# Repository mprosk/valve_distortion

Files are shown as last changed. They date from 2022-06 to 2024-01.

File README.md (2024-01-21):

# Valve Distortion
Eurorack format reimplementation of the Safety Valve from Look Mum No Computer

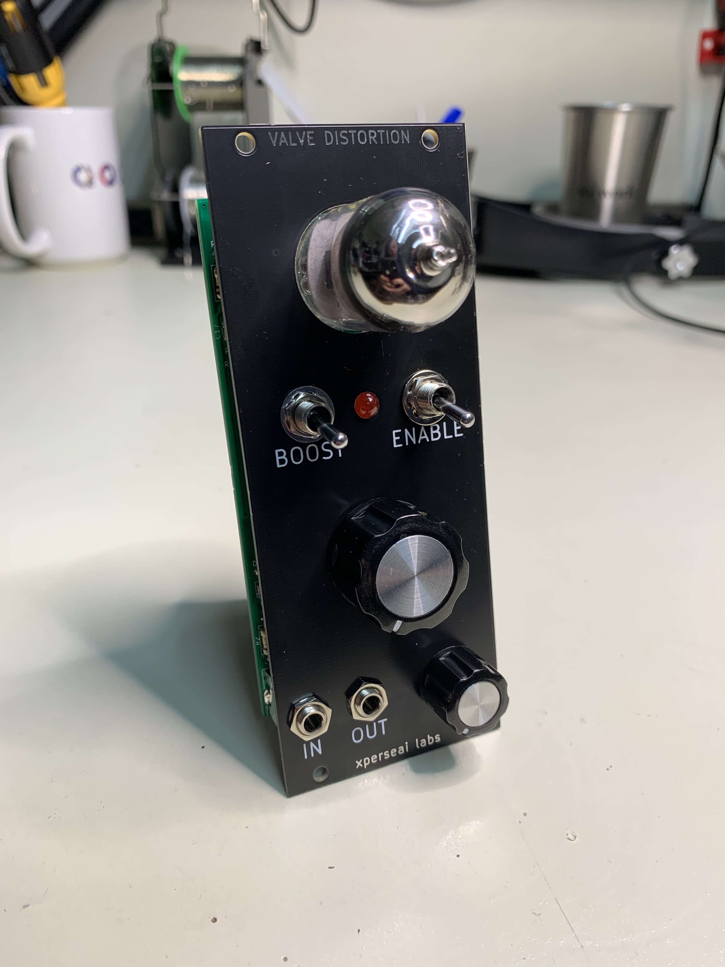
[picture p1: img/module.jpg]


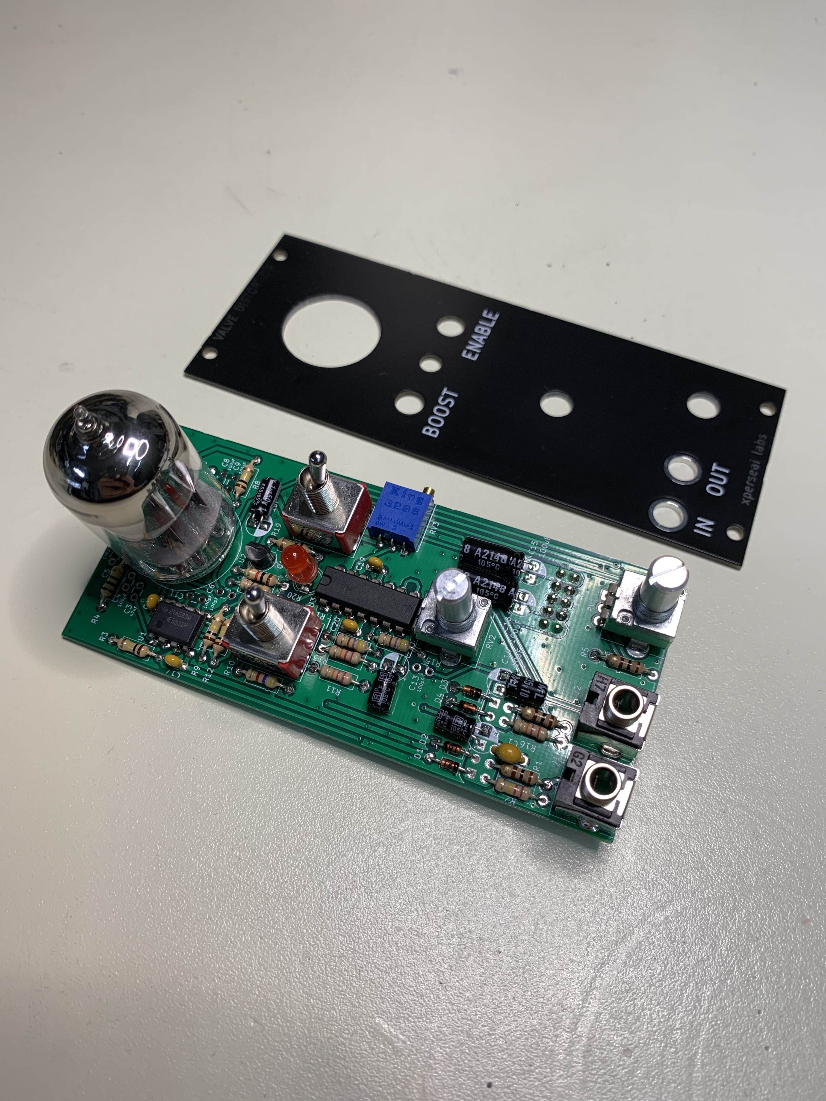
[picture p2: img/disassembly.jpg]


## Assembly Instructions

**Step 1:** Solder all resistors and diodes. Resistor values are marked on the silkscreen. **Be sure to get the correct orientation of the diodes!**

**Step 2:** Solder the ceramic capacitors. Ceramic capacitor values are marked on the silkscreen, *with the exception of 0.1uF / 100nF which are unlabeled*

**Step 3:** Solder the electrolytic capacitors. Capacitor values are marked on the silkscreen. **Be sure to get the correct polarity of the capacitors!** The white silkscreen fill indicates the negative leg of the capacitor. Capacitors should be folded down as shown above.

**Step 4:** Solder the ICs, transistor, trim pot, and 10pin power connector. **Be sure to get the correct orientation of the ICs!** Match the U shaped indent on the chip to the marking on the IC. The trim pot should be mounted sideways as shown above. The power connector should be mounted on the back of the PCB. **Make sure to get the correct orientation of the connector housing!**

**Step 5:** Place the switches, potentiometers, red 5mm LED, jacks, and tube in their respective locations in the PCB **but do not solder them yet!** First, place the faceplate over the controls and screw on the mounting hardware for each component. Note that due to slight hight differences between the parts, the nuts may not screw down all the way. **Do not over-tighten the mounting hardware as this may cause unwanted flexing of the PCBs.** You can use a rubber band or similar to hold everything together while handling. Push the legs of the LED from the back so that it just sticks through the front panel. Bend the legs from the back to hold it in place. **Be sure you have the correct polarity of the LED.**

**Step 6:** Once all the mounting hardware is secured, solder the switches, tube, LED, jacks, and potentiometers in place.

**Step 7:** Push the 3mm clear LED through the hole on the back of the PCB underneath the tube. Bend the leads such that they reach their connection points and cut them to length. **Be sure you have the correct polarity of the LED!** Solder the LED in place

**Step 8:** Put the knobs on to the potentiometers

**Step 9:** Power the module up and apply a signal to the input. Adjust the trim pot such that the LED underneath the tube illuminates when there is signal but is off when there is not. Note that sometimes the EMC of the LED can get picked up by the tube and cause an audible noise. If this occurs, adjust the trim pot such that the LED does not illuminate regardless of the signal level.

**Step 10:** Enjoy your gnarly new distortion module!

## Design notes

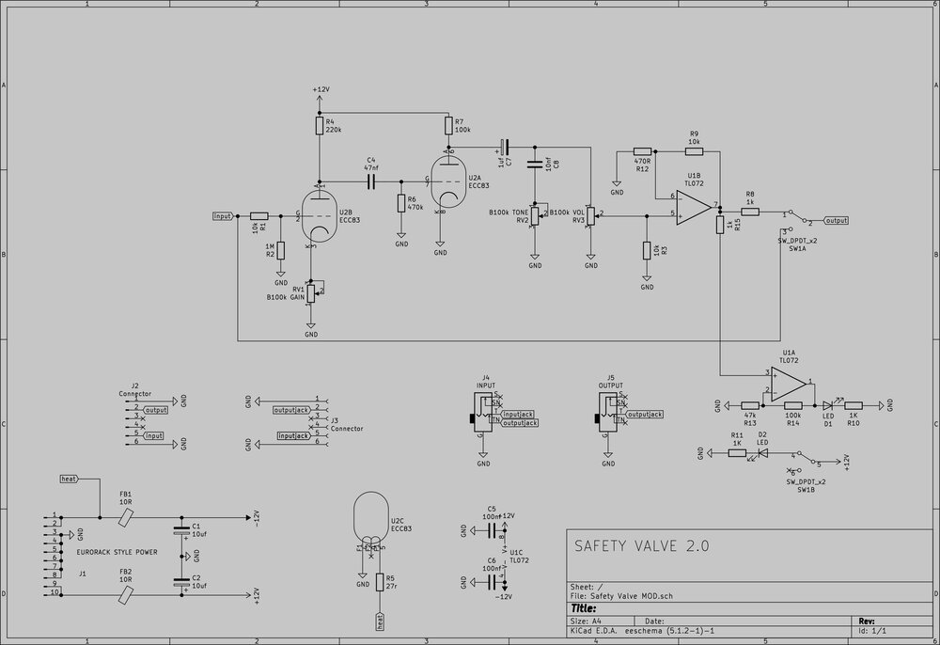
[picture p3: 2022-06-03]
datasheets/Safety+Valve+2.0+Schematic.jpg

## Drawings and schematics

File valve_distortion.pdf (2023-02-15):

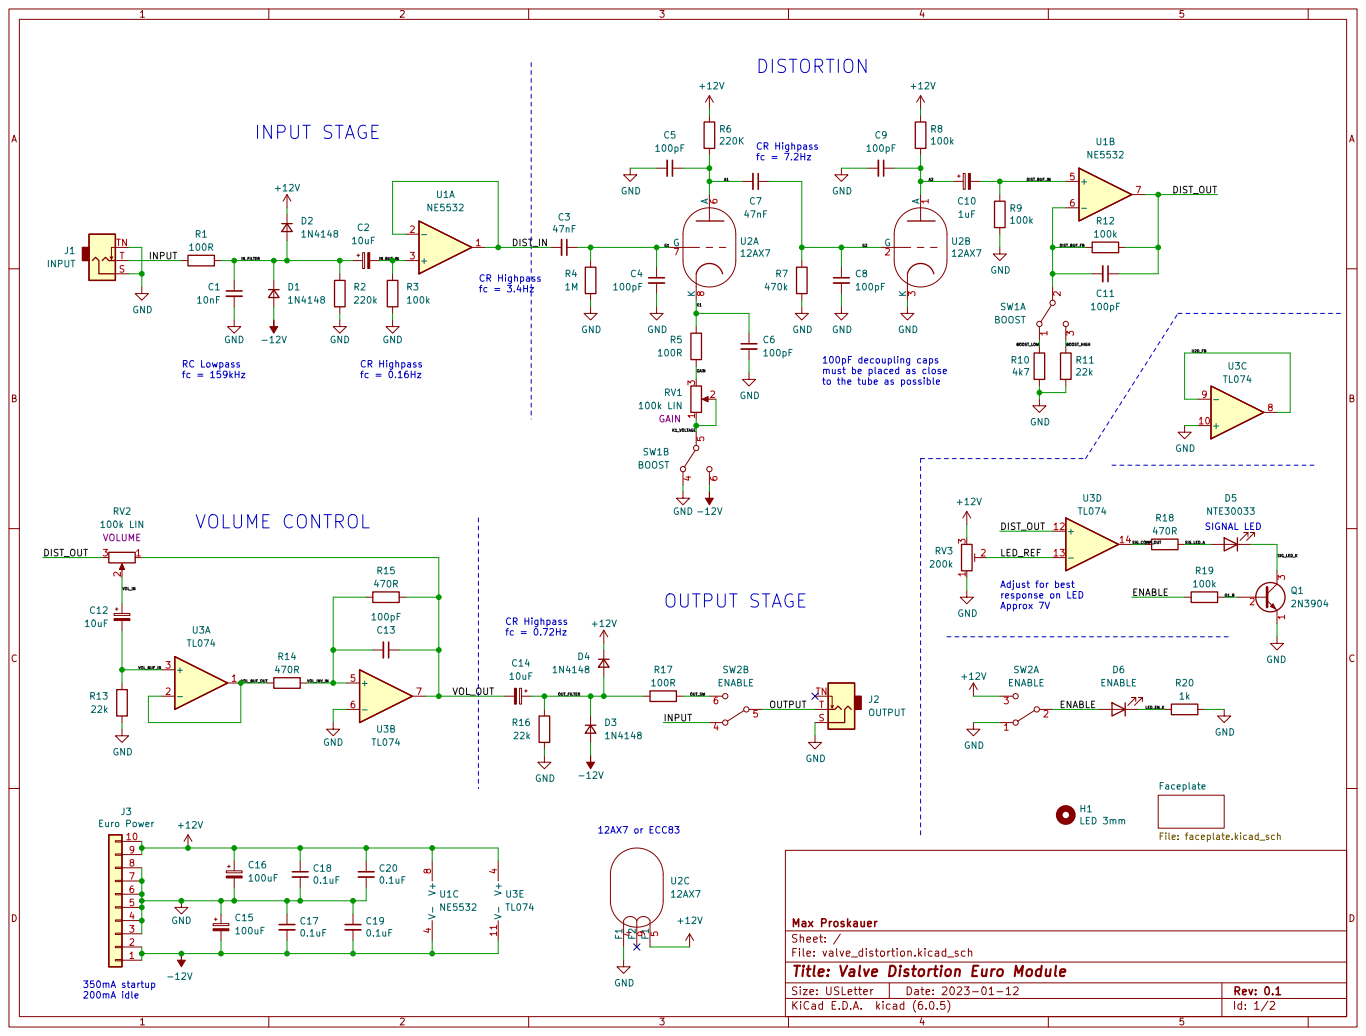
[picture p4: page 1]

100pF decoupling caps
must be placed as close
to the tube as possible

Id: 1/2 Title: Valve Distortion Euro Module

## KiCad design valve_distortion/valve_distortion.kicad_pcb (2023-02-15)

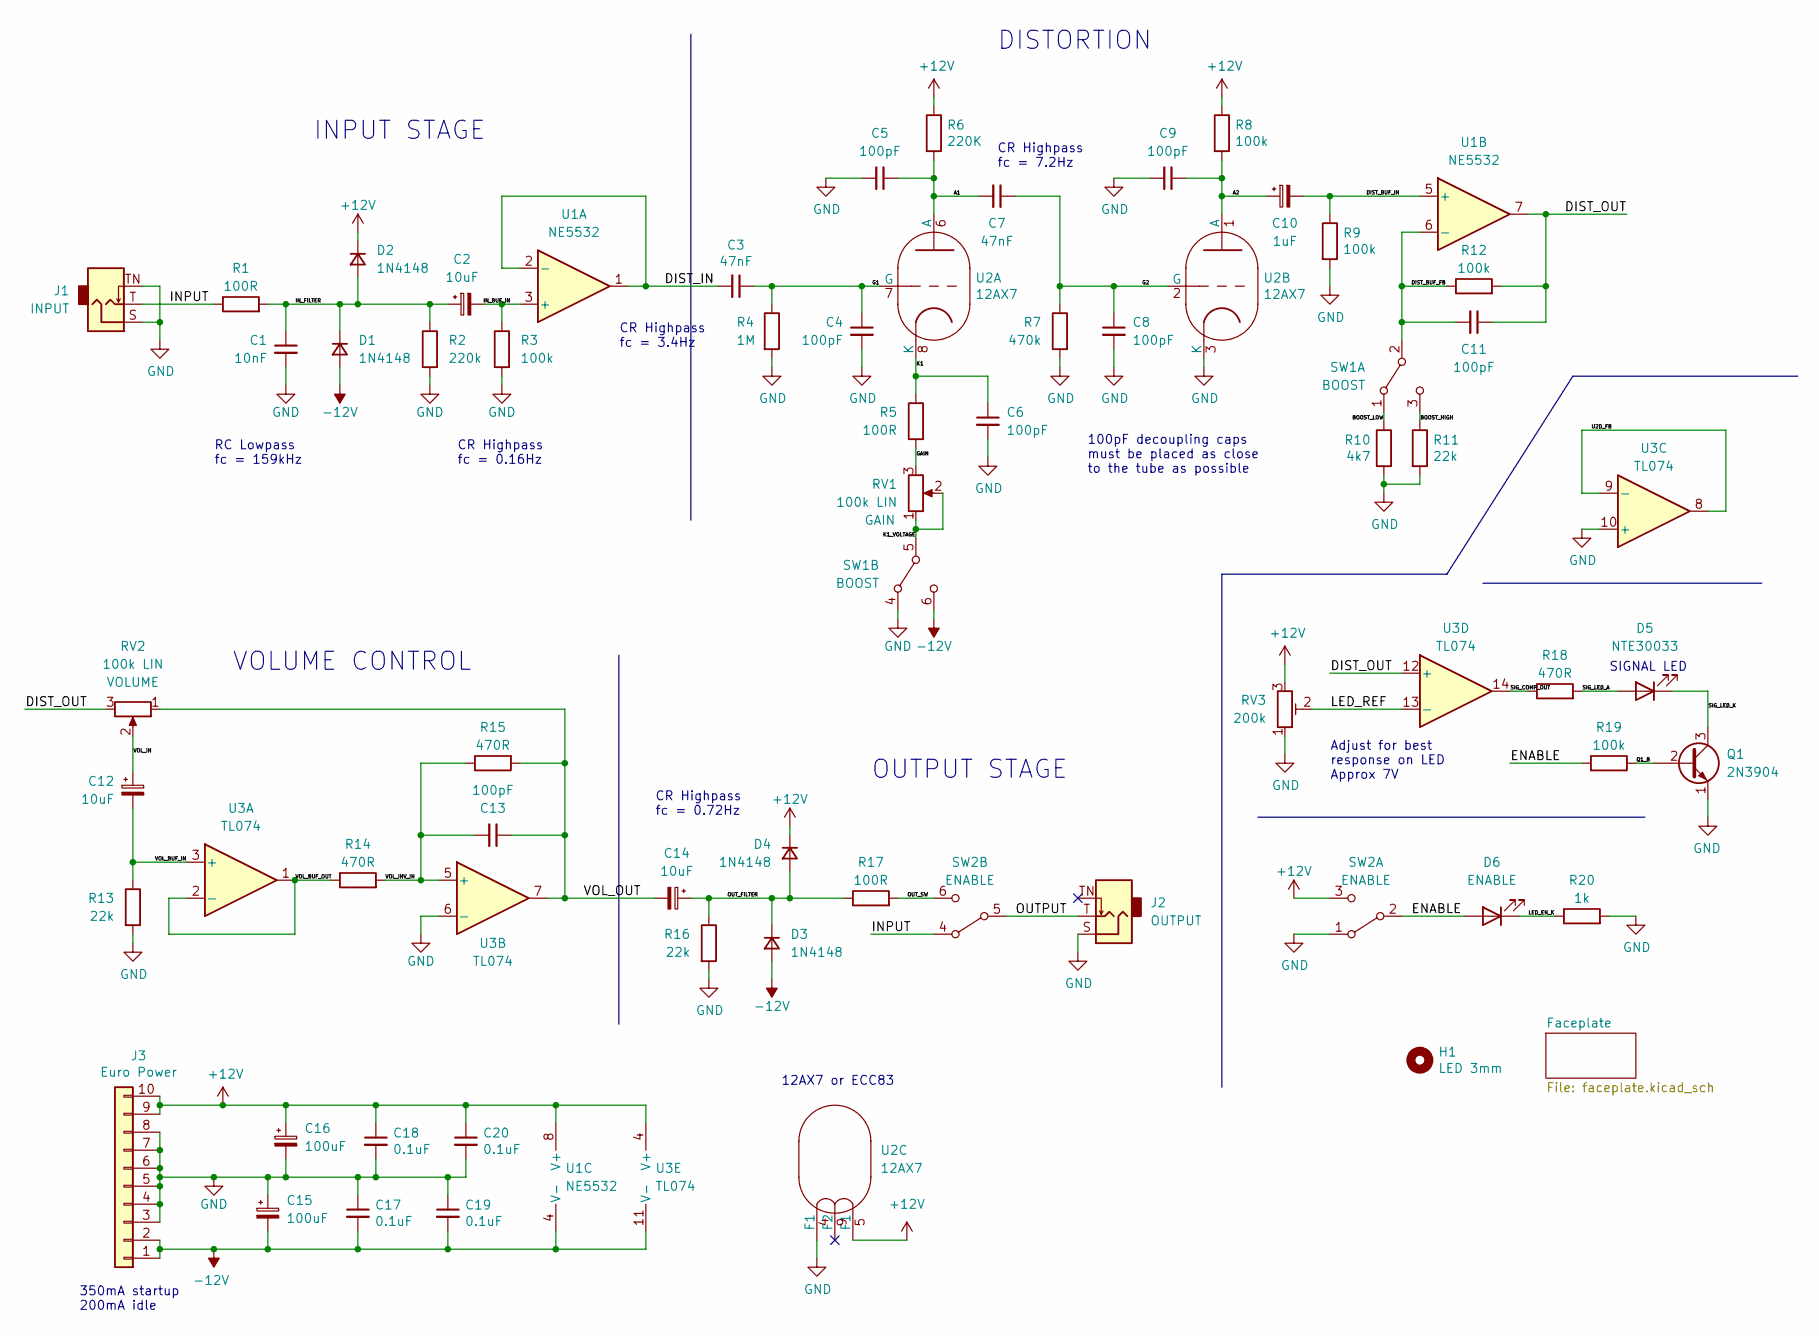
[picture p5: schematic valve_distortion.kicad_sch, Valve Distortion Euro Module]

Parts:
C1: 10nF; C_Disc_D4.3mm_W1.9mm_P5.00mm
C2, C12, C14: 10uF; CP_Radial_D5.0mm_P2.50mm
C3, C7: 47nF; C_Disc_D3.0mm_W1.6mm_P2.50mm
C4, C5, C6, C8, C9, C11, C13: 100pF; C_Disc_D3.0mm_W1.6mm_P2.50mm
C10: 1uF; CP_Radial_D5.0mm_P2.50mm
C15, C16: 100uF; CP_Radial_D5.0mm_P2.50mm
C17, C18, C19, C20: 0.1uF; C_Disc_D3.0mm_W1.6mm_P2.50mm
D1, D2, D3, D4: 1N4148; D_DO-34_SOD68_P7.62mm_Horizontal
D5: NTE30033; LED_D3.0mm_Clear
D6: ENABLE; LED_D5.0mm
H1: LED 3mm; Hole_LED_3mm
J1: INPUT; Jack_3.5mm_QingPu_WQP-PJ301BM
J2: OUTPUT; Jack_3.5mm_QingPu_WQP-PJ301BM
J3: Euro Power; IDC-Header_2x05_P2.54mm_Vertical
Q1: 2N3904; TO-92_Inline
R1, R5, R17: 100R; R_Axial_DIN0207_L6.3mm_D2.5mm_P10.16mm_Horizontal
R2: 220k; R_Axial_DIN0207_L6.3mm_D2.5mm_P10.16mm_Horizontal
R3, R8, R9, R12, R19: 100k; R_Axial_DIN0207_L6.3mm_D2.5mm_P10.16mm_Horizontal
R4: 1M; R_Axial_DIN0207_L6.3mm_D2.5mm_P10.16mm_Horizontal
R6: 220K; R_Axial_DIN0207_L6.3mm_D2.5mm_P10.16mm_Horizontal
R7: 470k; R_Axial_DIN0207_L6.3mm_D2.5mm_P10.16mm_Horizontal
R10: 4k7; R_Axial_DIN0207_L6.3mm_D2.5mm_P10.16mm_Horizontal
R11, R13, R16: 22k; R_Axial_DIN0207_L6.3mm_D2.5mm_P10.16mm_Horizontal
R14, R15, R18: 470R; R_Axial_DIN0207_L6.3mm_D2.5mm_P10.16mm_Horizontal
R20: 1k; R_Axial_DIN0207_L6.3mm_D2.5mm_P10.16mm_Horizontal
RV1, RV2: 100k LIN; Potentiometer_TT_P0915N
RV3: 200k; Potentiometer_Trim_Horizontal
SW1: BOOST; Switch_DPDT
SW2: ENABLE; Switch_DPDT
U1: NE5532; DIP-8_W7.62mm
U2: 12AX7; Valve_ECC-83-1
U3: TL074; DIP-14_W7.62mm

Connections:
+12V: C16.1, C18.1, C20.1, D2.1 (K), D4.1 (K), J3.9, J3.10, R6.1, R8.1, RV3.3, SW2.3 (C), U1.8 (V+), U2.5 (F1), U3.4 (V+)
-12V: C15.2, C17.2, C19.2, D1.2 (A), D3.2 (A), J3.1, J3.2, SW1.6 (C), U1.4 (V-), U3.11 (V-)
/A1: C5.1, C7.2, R6.2, U2.6 (A)
/A2: C9.1, C10.1, R8.2, U2.1 (A)
/BOOST_HIGH: R11.1, SW1.3 (C)
/BOOST_LOW: R10.1, SW1.1 (A)
/DIST_BUF_FB: C11.2, R12.1, SW1.2 (B), U1.6 (-)
/DIST_BUF_IN: C10.2, R9.1, U1.5 (+)
/DIST_IN: C3.2, U1.1, U1.2 (-)
/DIST_OUT: C11.1, R12.2, RV2.3, U1.7, U3.12 (+)
/ENABLE: D6.2 (A), R19.2, SW2.2 (B)
/G1: C3.1, C4.1, R4.1, U2.7 (G)
/G2: C7.1, C8.1, R7.1, U2.2 (G)
/GAIN: R5.2, RV1.3
/INPUT: J1.T, R1.1, SW2.4 (A)
/IN_BUF_IN: C2.2, R3.1, U1.3 (+)
/IN_FILTER: C1.1, C2.1, D1.1 (K), D2.2 (A), R1.2, R2.1
/K1: C6.1, R5.1, U2.8 (K)
/K1_VOLTAGE: RV1.1, RV1.2, SW1.5 (B)
/LED_EN_K: D6.1 (K), R20.1
/LED_REF: RV3.2, U3.13 (-)
/OUTPUT: J2.T, SW2.5 (B)
/OUT_FILTER: C14.1, D3.1 (K), D4.2 (A), R16.1, R17.1
/OUT_SW: R17.2, SW2.6 (C)
/Q1_B: Q1.2 (B), R19.1
/SIG_COMP_OUT: R18.1, U3.14
/SIG_LED_A: D5.2 (A), R18.2
/SIG_LED_K: D5.1 (K), Q1.3 (C)
/U2D_FB: U3.8, U3.9 (-)
/VOL_BUF_IN: C12.2, R13.1, U3.3 (+)
/VOL_BUF_OUT: R14.1, U3.1, U3.2 (-)
/VOL_IN: C12.1, RV2.2
/VOL_INV_IN: C13.2, R14.2, R15.1, U3.5 (+)
/VOL_OUT: C13.1, C14.2, R15.2, RV2.1, U3.7
GND: C1.2, C4.2, C5.2, C6.2, C8.2, C9.2, C15.1, C16.2, C17.1, C18.2, C19.1, C20.2, J1.S, J1.TN, J2.S, J3.3, J3.4, J3.5, J3.6, J3.7, J3.8, Q1.1 (E), R2.2, R3.2, R4.2, R7.2, R9.2, R10.2, R11.2, R13.2, R16.2, R20.2, RV3.1, SW1.4 (A), SW2.1 (A), U2.3 (K), U2.4 (F1), U3.6 (-), U3.10 (+)

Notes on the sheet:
CR Highpass fc = 0.16Hz
VOLUME CONTROL
CR Highpass fc = 3.4Hz
12AX7 or ECC83
Adjust for best response on LED Approx 7V
DISTORTION
RC Lowpass fc = 159kHz
CR Highpass fc = 0.72Hz
INPUT STAGE
100pF decoupling caps must be placed as close to the tube as possible
OUTPUT STAGE
CR Highpass fc = 7.2Hz
350mA startup 200mA idle
SIGNAL LED

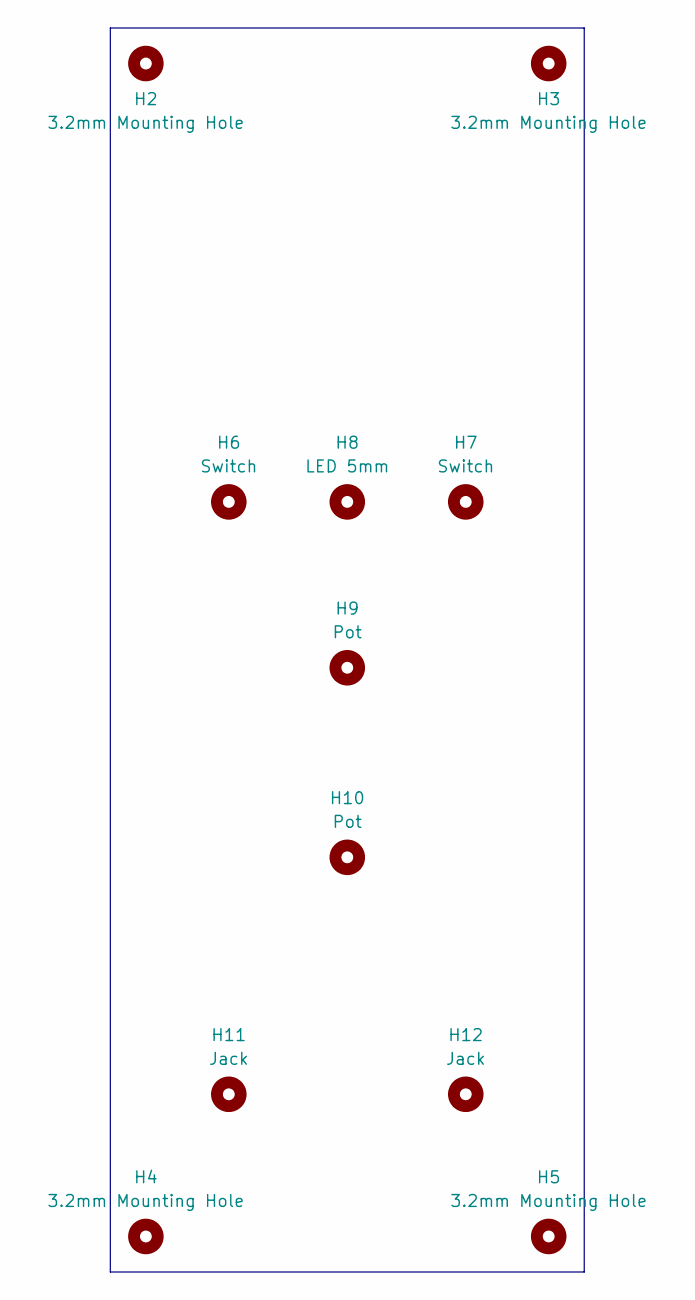
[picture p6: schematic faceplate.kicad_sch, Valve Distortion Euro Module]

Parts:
H2, H3, H4, H5: 3.2mm Mounting Hole; MountingHole_3.2mm_M3
H6, H7: Switch; Hole_Toggle_Switch
H8: LED 5mm; Hole_LED_5mm
H9, H10: Pot; Hole_Pot
H11, H12: Jack; Hole_Jack_3.5mm

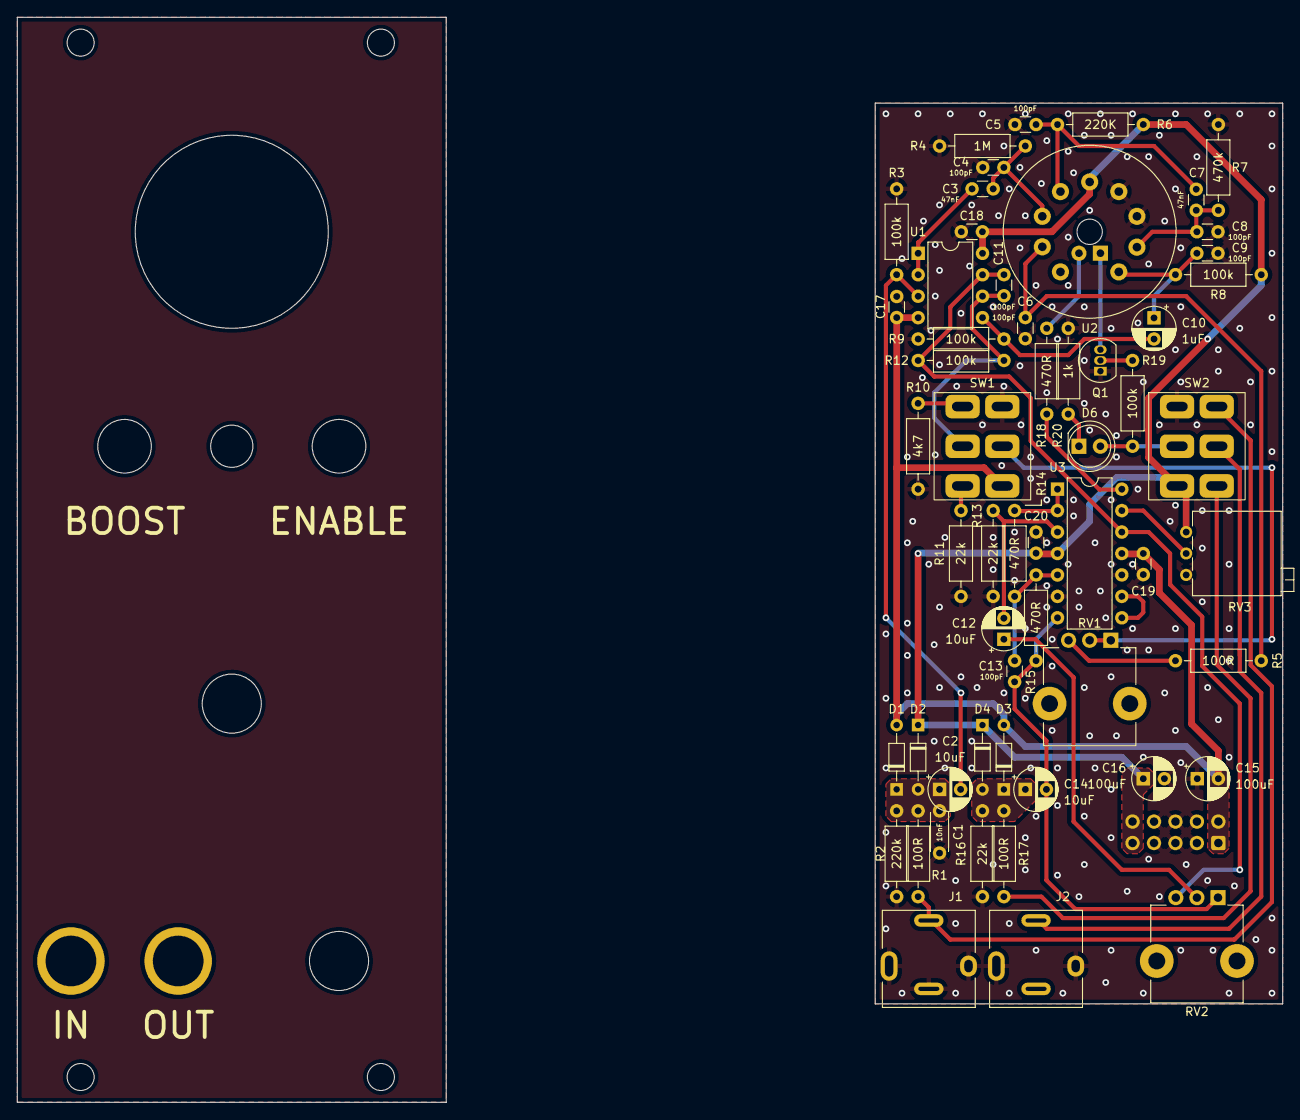
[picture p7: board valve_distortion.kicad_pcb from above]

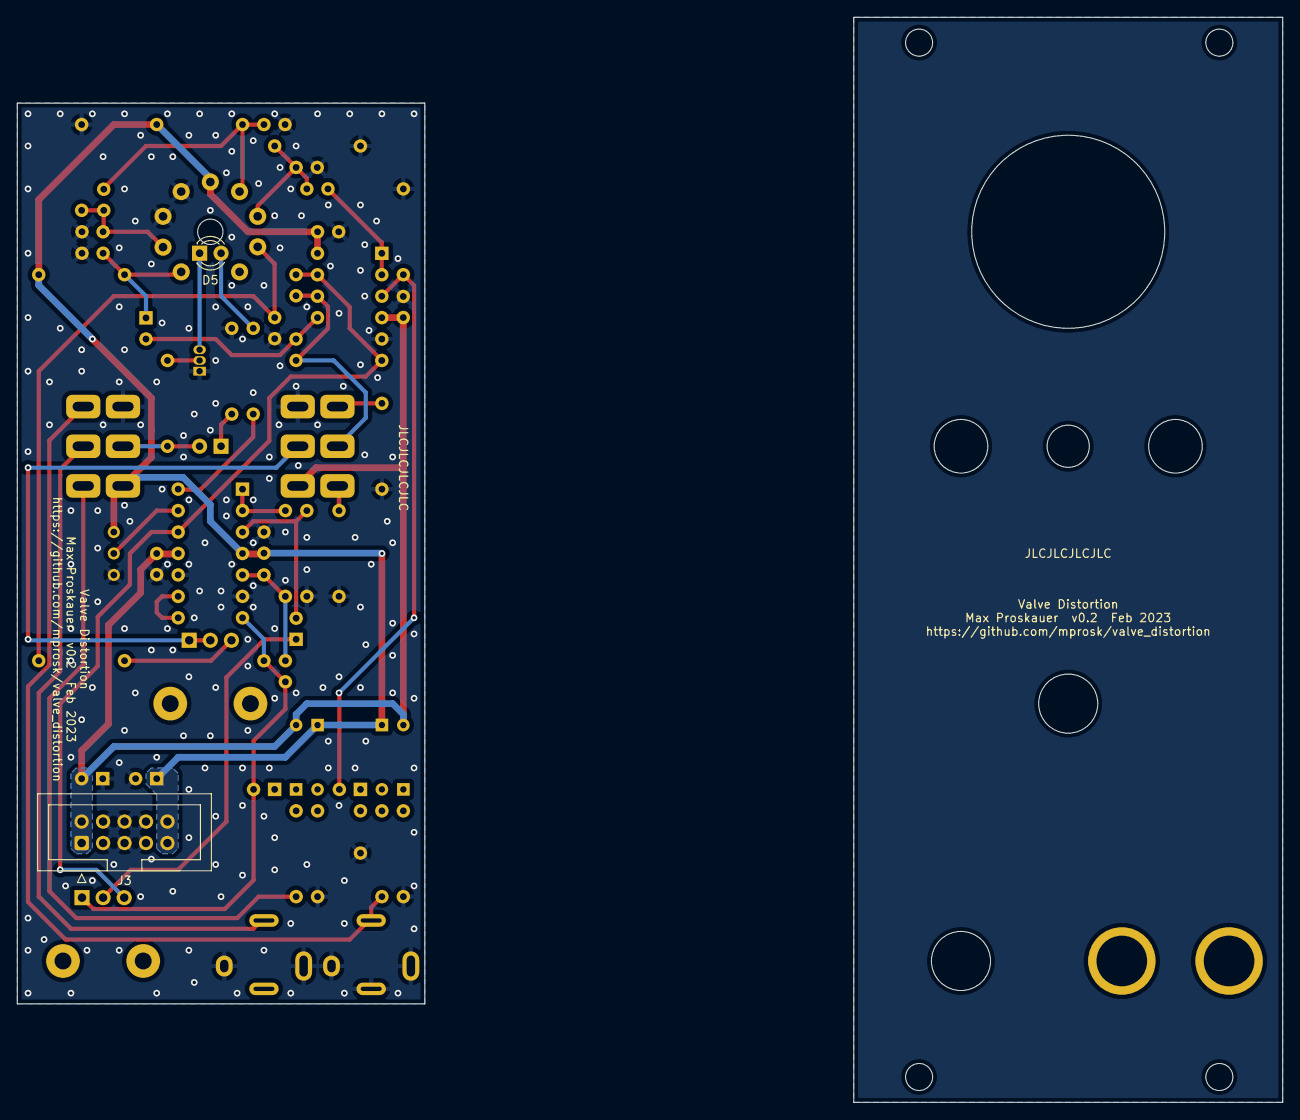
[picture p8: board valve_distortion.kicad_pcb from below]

Board: 2 copper layers, 48.3 x 106.7 mm, 70 parts (2 on the bottom side), 35 nets.

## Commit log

2022-06-03 Import files from deprecated repo and update to kicad6
    [faceplate.kicad_sch, valve_distortion.kicad_pcb, valve_distortion.kicad_sch]
2023-01-21 Add complete files for valve distortion euro module
    [faceplate.kicad_sch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]
2023-02-15 Fix rev1 pcb issues
    [valve_distortion-B_Cu.gbr, valve_distortion-B_Mask.gbr, valve_distortion-B_Silkscreen.gbr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]
2024-01-21 Add assembly instructions to README
